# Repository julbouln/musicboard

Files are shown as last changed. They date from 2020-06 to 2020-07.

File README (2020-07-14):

This project only use a CODEC, a QuadSPI NOR-flash and a STM32F7 microcontroller to provide a complete MIDI + audio USB soundcard.

Continuation of https://github.com/julbouln/stm32f7discovery_midi_synth prototype. It now uses a memory and computing optimized version of https://github.com/schellingb/TinySoundFont and includes STM32 cubemx source code. A dedicated custom board is also provided even though STM32F746 discovery board is supported by the firmware.

Features:
- Composite USB audio, USB MIDI and USB mass storage
- Integrated SF2 MIDI syntheziser
- Easy SF2 soundfont customization with USB mass storage
- Mixed MIDI synthesis and raw audio

Custom board with minimal requirements:
- STM32F746VET6 LQFP100 320kb ram + 512kb flash
- S25FL256S 32mb nor flash
- WM8731 codec

Update SF2 font (Linux):
When connected, Linux should show the Flash as mass storage:
sd 6:0:0:0: [sdb] 8192 4096-byte logical blocks: (33.6 MB/32.0 MiB)
sd 6:0:0:0: [sdb] Write Protect is off
sd 6:0:0:0: [sdb] Mode Sense: 22 00 00 00
sd 6:0:0:0: [sdb] Write cache: disabled, read cache: enabled, doesn't support DPO or FUA
sd 6:0:0:0: [sdb] Attached SCSI removable disk
You just need to dd the sf2 file to the disk (can take several minutes):
# dd if=yourfont.sf2 of=/dev/sdb bs=4096

Update SF2 font (balena Etcher)
You can also update the SF2 using balena Etcher https://www.balena.io/etcher/. This program is intended for OS image, but you can use it for SF2:
- you will need to rename your extension from .sf2 to .bin so Etcher can accept the file
- Etcher will warn you that the image is not an OS, just hit continue and select SF2 ROM drive

LED should blink if the font is properly recognized.

Notes:
Firmware tested with arm-none-eabi-gcc 9.2.1 20191025
SF2 fonts tested:
- TimGM6mb http://www.timbrechbill.com/saxguru/Timidity.php
- GeneralUser GS http://www.schristiancollins.com/generaluser.php (custom board only, 32mb font)
Default make for STM32F746-DISCO board, use "make BOARD=MUSICBOARD" for custom board firmware.

TODO:
- bug: synthesis sometimes make a "click" noise
- feature: TinySoundFont does not fully implement SF2 (modulators)
- feature: Add MIDI IN/OUT uart interfaces
- feature: USB-MIDI to MIDI interface (add MIDI-IN and MIDI-OUT)
- feature: Audio IN
- feature: Add sysex for chorus & reverb control

Sources:
- https://github.com/STMicroelectronics/STM32CubeF7

SF2:
- https://github.com/schellingb/TinySoundFont

USB audio with asynchronous feedback
- https://github.com/dragonman225/stm32f469-usbaudio
- https://github.com/ada-sound/X-CUBE-USB-AUDIO
- https://github.com/Lefucjusz/Lefucjusz-USB-DAC

USB composite:
- https://github.com/sanuch14/STM32_CompositeHID_CDC

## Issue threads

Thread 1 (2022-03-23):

Ceci n'est pas un probleme

ukmaker, 2022-03-23:
Hi @julbouln and thanks for your work on this!

I'm about to try to port it to the Electrosmith Daisy Seed - any gotchas I should be aware of?

If you haven't seen it, it's an STM32H750 based board with WM8731, QSPI flash and RAM ( https://github.com/electro-smith/Hardware/blob/master/reference/daisy_seed/Daisy_Seed_Rev5_sch.pdf )

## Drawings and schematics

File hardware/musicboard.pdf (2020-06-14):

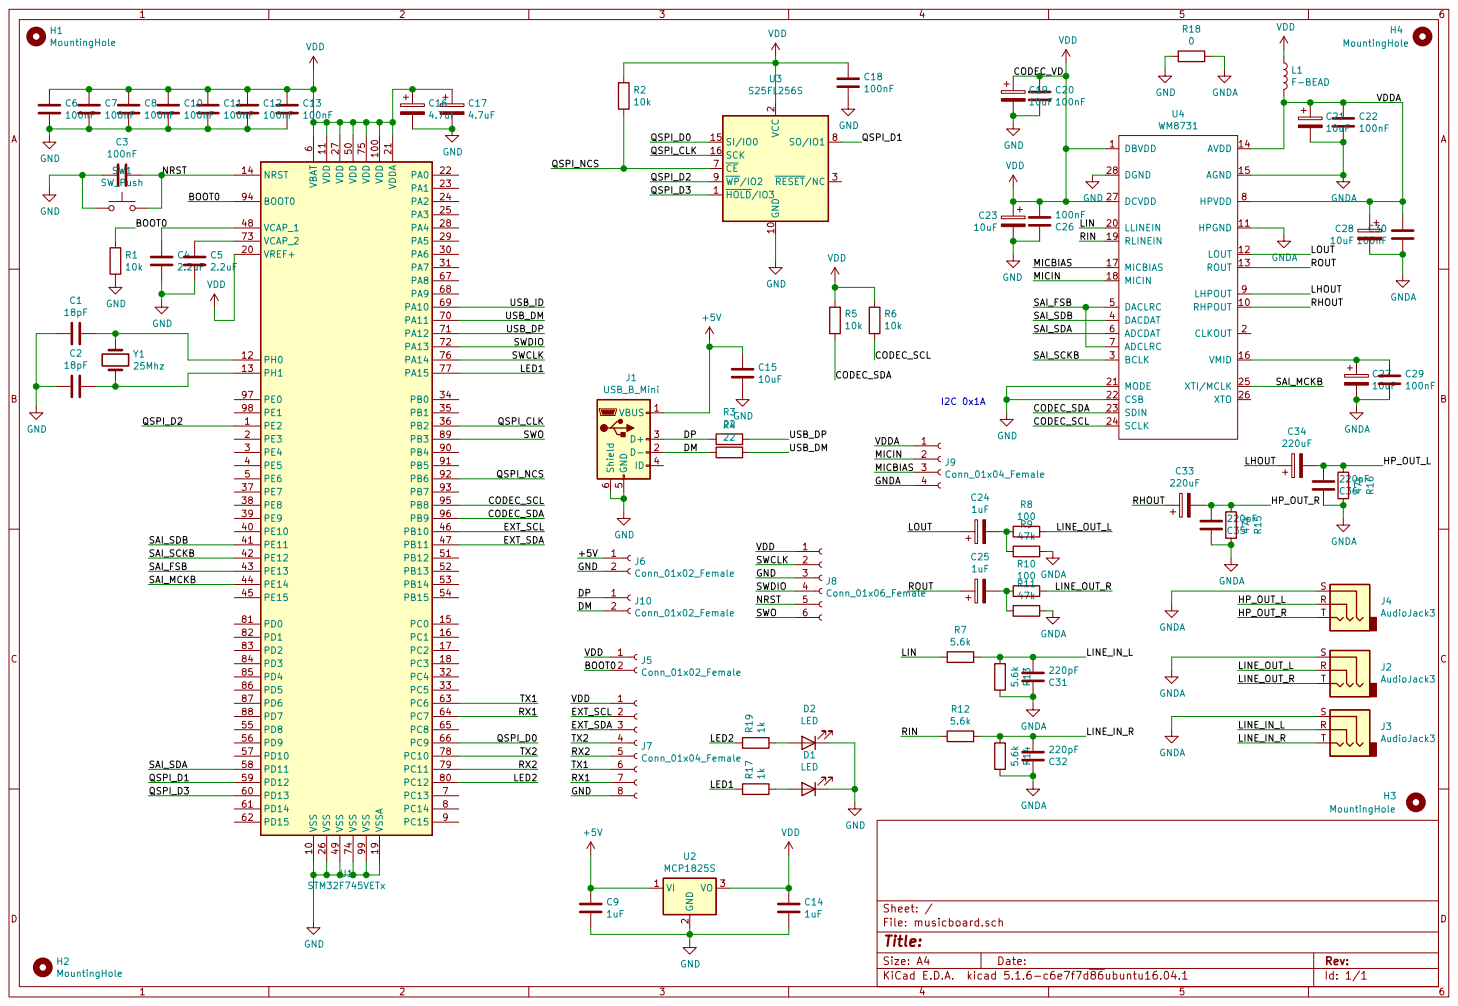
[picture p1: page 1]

2 RESET/NC 3 CE 7 SO/IO1 8 WP/IO2 9 U3 S25FL256S

6 VCAP_1 48 VCAP_2 73 VDD 100 VDD 11 VDD 27 VDD 50 VDD 75 VDDA 21 VREF+ 20 VSS 10 VSS 26 VSS 49 VSS 74 VSS 99 VSSA 19 U1 STM32F745VETx 1

Id: 1/1 Title: File: musicboard.sch Sheet: /

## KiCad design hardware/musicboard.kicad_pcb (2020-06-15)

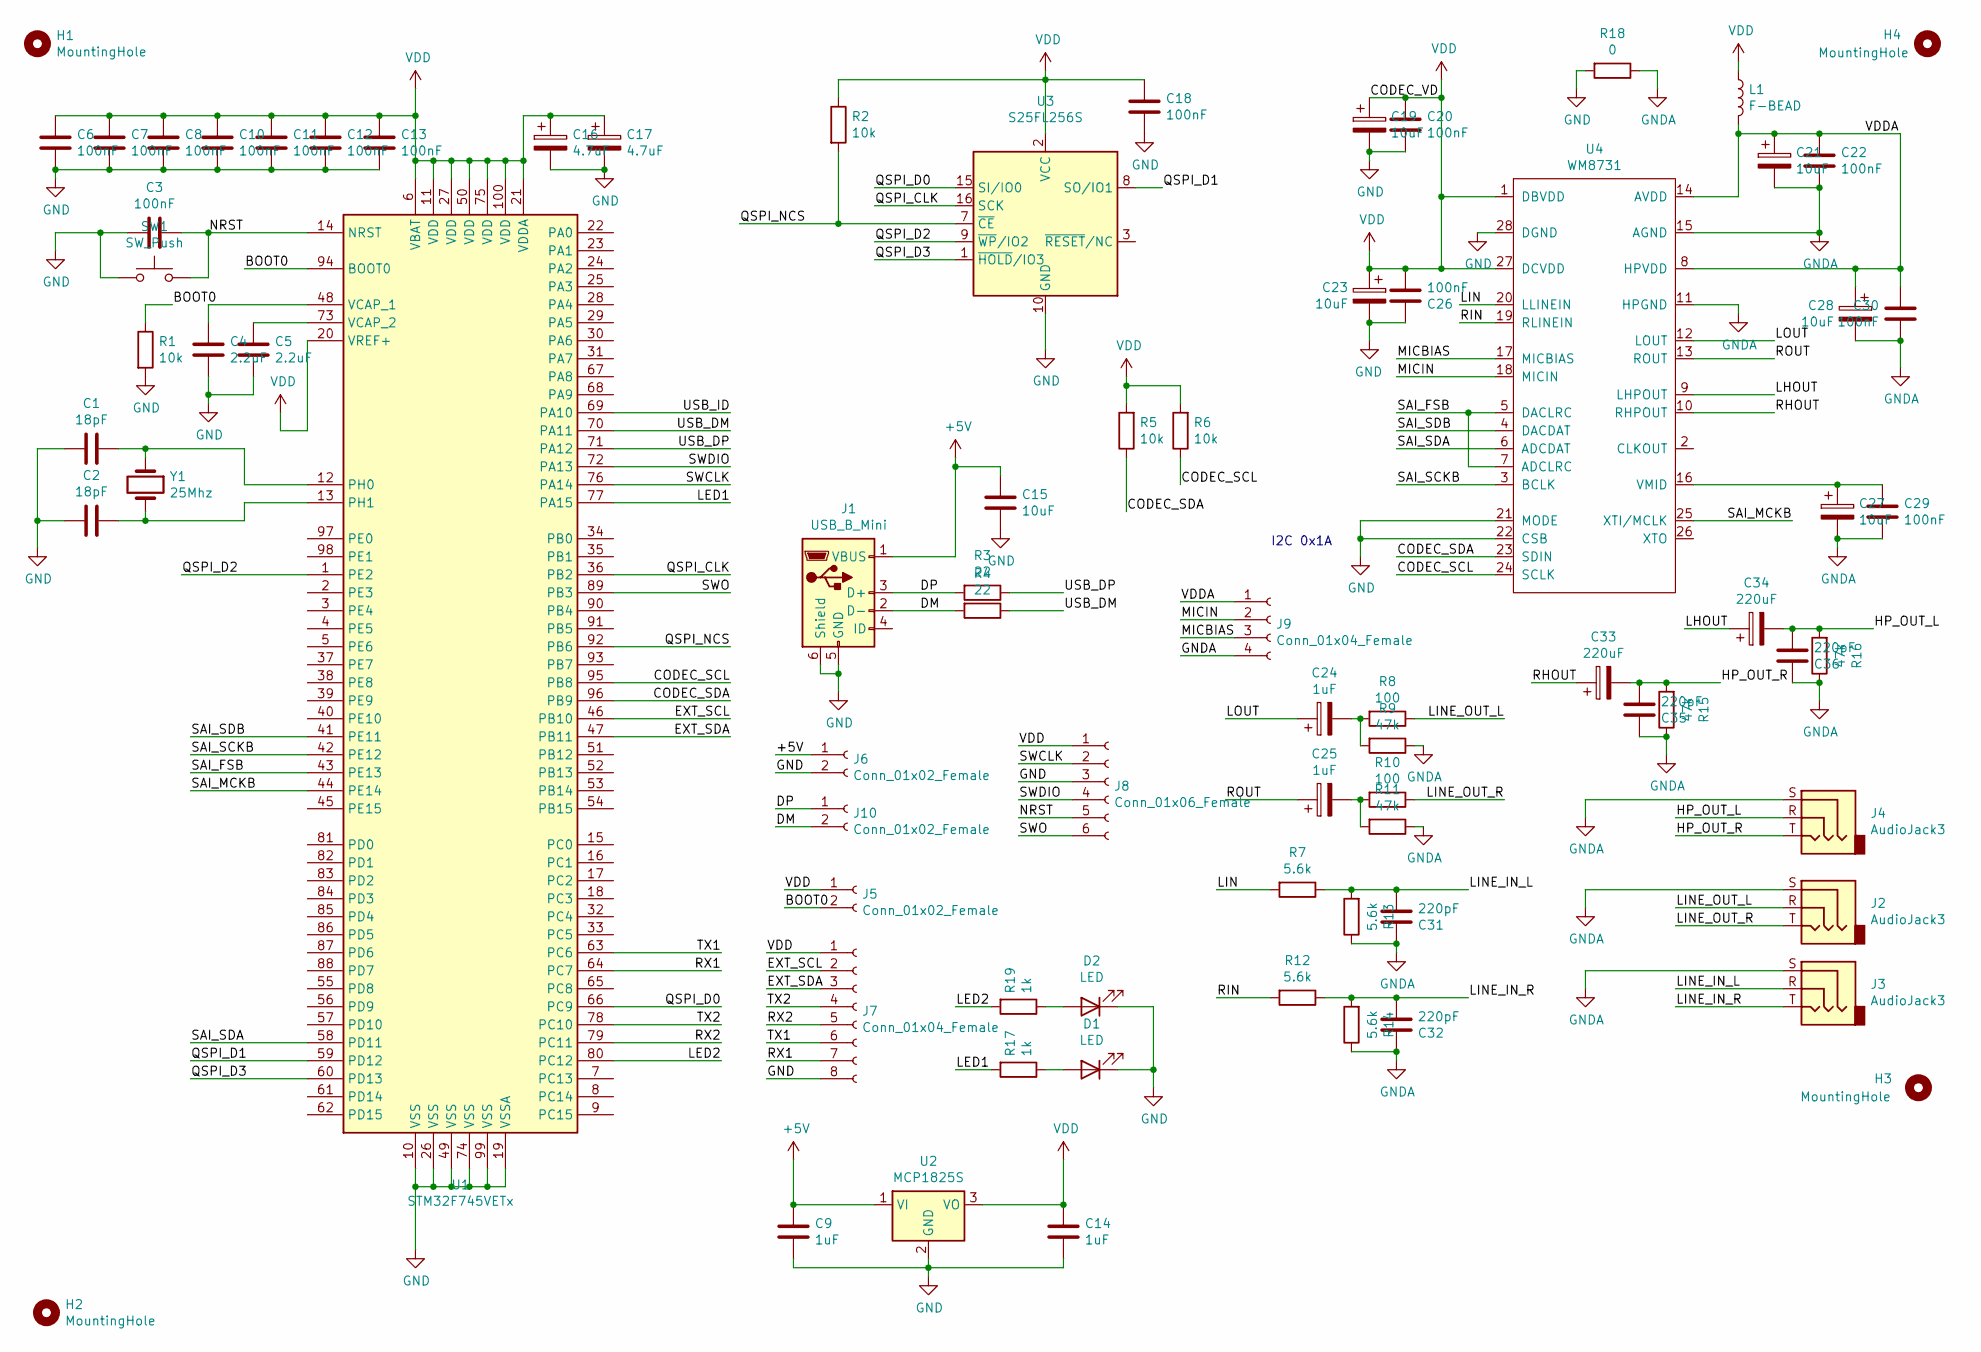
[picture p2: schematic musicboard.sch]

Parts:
C1, C2: 18pF; C_0603_1608Metric_Pad1.05x0.95mm_HandSolder
C3, C6, C7, C8, C10, C11, C12, C13, C18, C20, C22, C26, C29, C30: 100nF; C_0603_1608Metric_Pad1.05x0.95mm_HandSolder
C4, C5: 2.2uF; C_0603_1608Metric_Pad1.05x0.95mm_HandSolder
C9, C14: 1uF; C_0603_1608Metric_Pad1.05x0.95mm_HandSolder
C15, C19, C21, C23, C27, C28: 10uF; C_0805_2012Metric_Pad1.15x1.40mm_HandSolder
C16, C17: 4.7uF; C_0805_2012Metric_Pad1.15x1.40mm_HandSolder
C24, C25: 1uF; C_Elec_4x5.4
C31, C32, C35, C36: 220pF; C_0603_1608Metric_Pad1.05x0.95mm_HandSolder
C33, C34: 220uF; C_Elec_6.3x5.4
D1, D2: LED; LED_0603_1608Metric_Pad1.05x0.95mm_HandSolder
H1, H2, H3, H4: MountingHole; MountingHole_2.7mm_M2.5
J1: USB_B_Mini; USB-mini-B-0548190519
J2, J3, J4: AudioJack3; Jack_3.5mm_CUI_SJ1-3535NG_Horizontal
J5, J6, J10: Conn_01x02_Female; PinHeader_1x02_P2.54mm_Vertical
J7: Conn_01x04_Female; PinHeader_1x08_P2.54mm_Vertical
J8: Conn_01x06_Female; PinHeader_1x06_P2.54mm_Vertical
J9: Conn_01x04_Female; PinHeader_1x04_P2.54mm_Vertical
L1: F-BEAD; L_0805_2012Metric_Pad1.15x1.40mm_HandSolder
R1, R2, R5, R6: 10k; R_0603_1608Metric_Pad1.05x0.95mm_HandSolder
R3, R4: 22; R_0603_1608Metric_Pad1.05x0.95mm_HandSolder
R7, R12, R13, R14: 5.6k; R_0603_1608Metric_Pad1.05x0.95mm_HandSolder
R8, R10: 100; R_0603_1608Metric_Pad1.05x0.95mm_HandSolder
R9, R11, R15, R16: 47k; R_0603_1608Metric_Pad1.05x0.95mm_HandSolder
R17, R19: 1k; R_0603_1608Metric_Pad1.05x0.95mm_HandSolder
R18: 0; R_0805_2012Metric_Pad1.15x1.40mm_HandSolder
SW1: SW_Push; SW_SPST_B3U-3000P
U1: STM32F745VETx; LQFP-100_14x14mm_P0.5mm
U2: MCP1825S; SOT-223-3_TabPin2
U3: S25FL256S; SOIC-16W_7.5x10.3mm_P1.27mm
U4: WM8731; SSOP-28_5.3x10.2mm_P0.65mm
Y1: 25Mhz; Crystal_SMD_5032-2Pin_5.0x3.2mm_HandSoldering

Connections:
+5V: C9.1, C15.1, J1.1 (VBUS), J6.1, U2.1 (VI)
/BOOT0: J5.2, R1.1, U1.94 (BOOT0)
/CODEC_SCL: R6.1, U1.95 (PB8), U4.24 (SCLK)
/CODEC_SDA: R5.1, U1.96 (PB9), U4.23 (SDIN)
/DM: J1.2 (D-), J10.2, R4.2
/DP: J1.3 (D+), J10.1, R3.2
/EXT_SCL: J7.2, U1.46 (PB10)
/EXT_SDA: J7.3, U1.47 (PB11)
/HP_OUT_L: C34.2, C36.2, J4.R, R16.2
/HP_OUT_R: C33.2, C35.2, J4.T, R15.2
/LED1: R17.2, U1.77 (PA15)
/LED2: R19.2, U1.80 (PC12)
/LHOUT: C34.1, U4.9 (LHPOUT)
/LIN: R7.2, U4.20 (LLINEIN)
/LINE_IN_L: C31.2, J3.R, R7.1, R13.2
/LINE_IN_R: C32.2, J3.T, R12.1, R14.2
/LINE_OUT_L: J2.R, R8.1
/LINE_OUT_R: J2.T, R10.1
/LOUT: C24.1, U4.12 (LOUT)
/MICBIAS: J9.3, U4.17 (MICBIAS)
/MICIN: J9.2, U4.18 (MICIN)
/NRST: C3.1, J8.5, SW1.2, U1.14 (NRST)
/QSPI_CLK: U1.36 (PB2), U3.16 (SCK)
/QSPI_D0: U1.66 (PC9), U3.15 (SI/IO0)
/QSPI_D1: U1.59 (PD12), U3.8 (SO/IO1)
/QSPI_D2: U1.1 (PE2), U3.9 (~WP~/IO2)
/QSPI_D3: U1.60 (PD13), U3.1 (~HOLD~/IO3)
/QSPI_NCS: R2.2, U1.92 (PB6), U3.7 (~CE)
/RHOUT: C33.1, U4.10 (RHPOUT)
/RIN: R12.2, U4.19 (RLINEIN)
/ROUT: C25.1, U4.13 (ROUT)
/RX1: J7.7, U1.64 (PC7)
/RX2: J7.5, U1.79 (PC11)
/SAI_FSB: U1.43 (PE13), U4.5 (DACLRC), U4.7 (ADCLRC)
/SAI_MCKB: U1.44 (PE14), U4.25 (XTI/MCLK)
/SAI_SCKB: U1.42 (PE12), U4.3 (BCLK)
/SAI_SDA: U1.58 (PD11), U4.6 (ADCDAT)
/SAI_SDB: U1.41 (PE11), U4.4 (DACDAT)
/SWCLK: J8.2, U1.76 (PA14)
/SWDIO: J8.4, U1.72 (PA13)
/SWO: J8.6, U1.89 (PB3)
/TX1: J7.6, U1.63 (PC6)
/TX2: J7.4, U1.78 (PC10)
/USB_DM: R4.1, U1.70 (PA11)
/USB_DP: R3.1, U1.71 (PA12)
/USB_ID: U1.69 (PA10)
/VDDA: C21.1, C22.1, C28.1, C30.1, J9.1, L1.2, U4.8 (HPVDD), U4.14 (AVDD)
GND: C1.2, C2.2, C3.2, C4.2, C5.2, C6.2, C7.2, C8.2, C9.2, C10.2, C11.2, C12.2, C13.2, C14.2, C15.2, C16.2, C17.2, C18.2, C19.2, C20.2, C23.2, C26.1, D1.1 (K), D2.1 (K), J1.5 (GND), J1.6 (Shield), J6.2, J7.8, J8.3, R1.2, R18.2, SW1.1, U1.10 (VSS), U1.19 (VSSA), U1.26 (VSS), U1.49 (VSS), U1.74 (VSS), U1.99 (VSS), U2.2 (GND), U3.10 (GND), U4.21 (MODE), U4.22 (CSB), U4.28 (DGND)
GNDA: C21.2, C22.2, C27.2, C28.2, C29.2, C30.2, C31.1, C32.1, C35.1, C36.1, J2.S, J3.S, J4.S, J9.4, R9.1, R11.1, R13.1, R14.1, R15.1, R16.1, R18.1, U4.11 (HPGND), U4.15 (AGND)
unnamed: C1.1, U1.12 (PH0), Y1.1
unnamed: C2.1, U1.13 (PH1), Y1.2
unnamed: C4.1, U1.48 (VCAP_1)
unnamed: C5.1, U1.73 (VCAP_2)
unnamed: C24.2, R8.2, R9.2
unnamed: C25.2, R10.2, R11.2
unnamed: C27.1, C29.1, U4.16 (VMID)
unnamed: D1.2 (A), R17.1
unnamed: D2.2 (A), R19.1
VDD: C6.1, C7.1, C8.1, C10.1, C11.1, C12.1, C13.1, C14.1, C16.1, C17.1, C18.1, C19.1, C20.1, C23.1, C26.2, J5.1, J7.1, J8.1, L1.1, R2.1, R5.2, R6.2, U1.6 (VBAT), U1.11 (VDD), U1.20 (VREF+), U1.21 (VDDA), U1.27 (VDD), U1.50 (VDD), U1.75 (VDD), U1.100 (VDD), U2.3 (VO), U3.2 (VCC), U4.1 (DBVDD), U4.27 (DCVDD)

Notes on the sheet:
I2C 0x1A

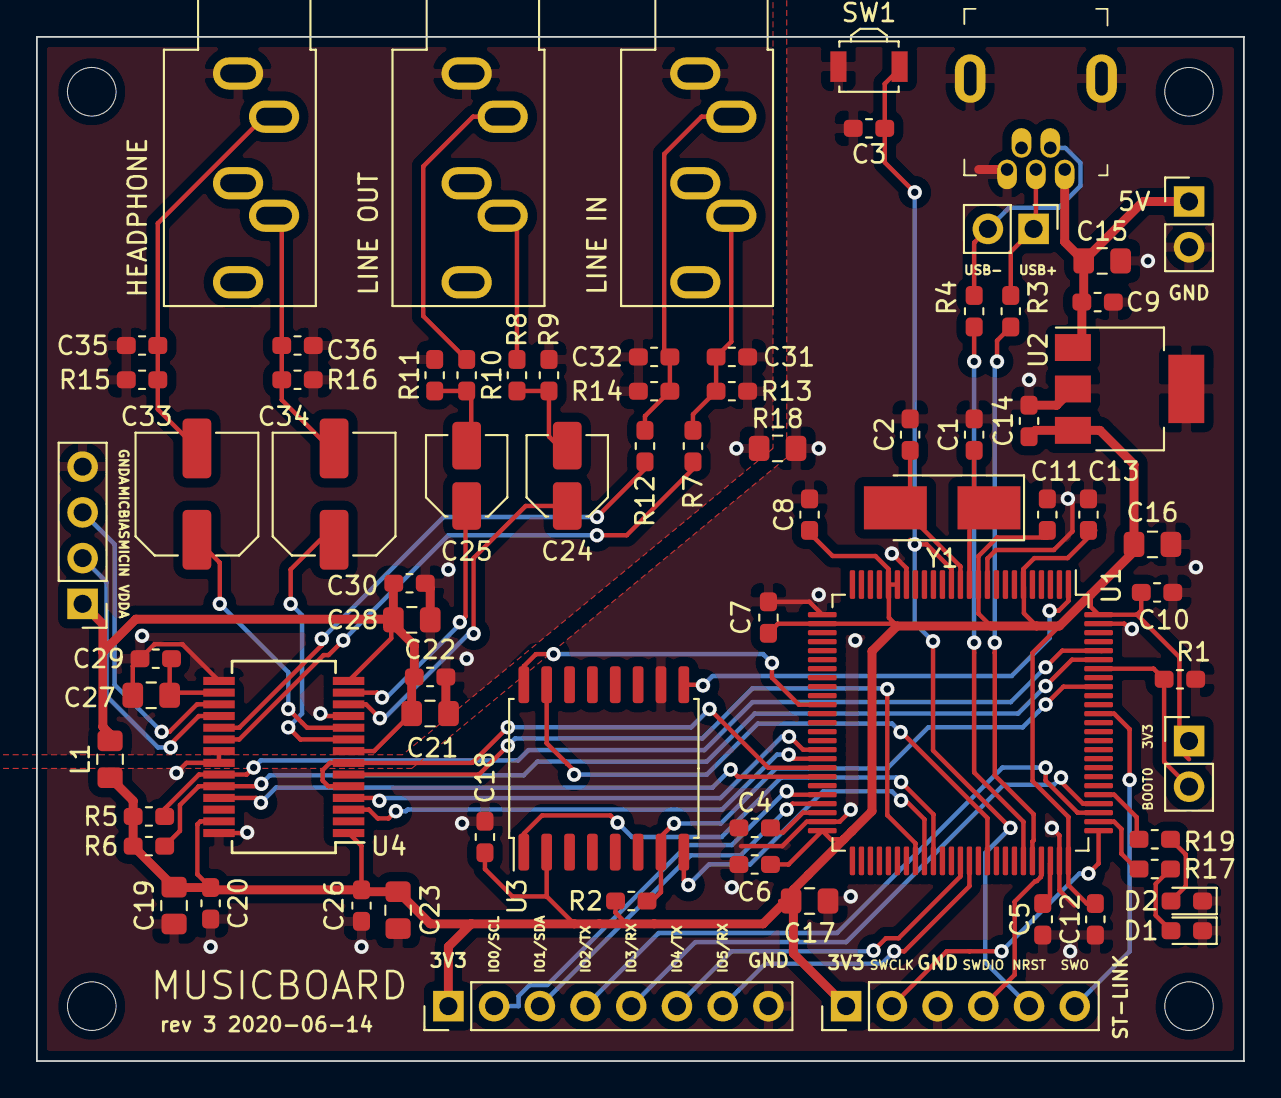
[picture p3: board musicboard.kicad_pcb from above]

Board: 2 copper layers, 67.1 x 56.9 mm, 78 parts (0 on the bottom side), 58 nets.

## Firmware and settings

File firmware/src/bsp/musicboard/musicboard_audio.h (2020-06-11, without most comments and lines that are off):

#define __MUSICBOARD_AUDIO_H
#ifdef __cplusplus
 extern "C" {
#endif
#include "wm8731.h"
#include "musicboard.h"
#define CODEC_AUDIOFRAME_SLOT_0123           SAI_SLOTACTIVE_0 | SAI_SLOTACTIVE_1 | SAI_SLOTACTIVE_2 | SAI_SLOTACTIVE_3
#define CODEC_AUDIOFRAME_SLOT_02             SAI_SLOTACTIVE_0 | SAI_SLOTACTIVE_2
#define CODEC_AUDIOFRAME_SLOT_13             SAI_SLOTACTIVE_1 | SAI_SLOTACTIVE_3
#define AUDIO_OUT_SAIx                           SAI2_Block_B
#define AUDIO_OUT_SAIx_CLK_ENABLE()              __HAL_RCC_SAI2_CLK_ENABLE()
#define AUDIO_OUT_SAIx_CLK_DISABLE()             __HAL_RCC_SAI2_CLK_DISABLE()
#define AUDIO_OUT_SAIx_SCK_AF                    GPIO_AF10_SAI2
#define AUDIO_OUT_SAIx_FS_SD_MCLK_AF             GPIO_AF10_SAI2
#define AUDIO_OUT_SAIx_MCLK_ENABLE()             __HAL_RCC_GPIOE_CLK_ENABLE()
#define AUDIO_OUT_SAIx_MCLK_GPIO_PORT            GPIOE
#define AUDIO_OUT_SAIx_MCLK_PIN                  GPIO_PIN_14
#define AUDIO_OUT_SAIx_SCK_SD_ENABLE()           __HAL_RCC_GPIOE_CLK_ENABLE()
#define AUDIO_OUT_SAIx_SCK_SD_GPIO_PORT          GPIOE
#define AUDIO_OUT_SAIx_SCK_PIN                   GPIO_PIN_12
#define AUDIO_OUT_SAIx_SD_PIN                    GPIO_PIN_11
#define AUDIO_OUT_SAIx_FS_ENABLE()               __HAL_RCC_GPIOE_CLK_ENABLE()
#define AUDIO_OUT_SAIx_FS_GPIO_PORT              GPIOE
#define AUDIO_OUT_SAIx_FS_PIN                    GPIO_PIN_13
#define AUDIO_OUT_SAIx_DMAx_CLK_ENABLE()         __HAL_RCC_DMA2_CLK_ENABLE()
#define AUDIO_OUT_SAIx_DMAx_STREAM               DMA2_Stream7
#define AUDIO_OUT_SAIx_DMAx_CHANNEL              DMA_CHANNEL_0
#define AUDIO_OUT_SAIx_DMAx_IRQ                  DMA2_Stream7_IRQn
#define AUDIO_OUT_SAIx_DMAx_PERIPH_DATA_SIZE     DMA_PDATAALIGN_HALFWORD
#define AUDIO_OUT_SAIx_DMAx_MEM_DATA_SIZE        DMA_MDATAALIGN_HALFWORD
#define DMA_MAX_SZE                              ((uint16_t)0xFFFF)
#define AUDIO_OUT_SAIx_DMAx_IRQHandler           DMA2_Stream7_IRQHandler
#define AUDIO_OUT_IRQ_PREPRIO                    ((uint32_t)0x0E)
#define AUDIO_IN_SAIx                            SAI2_Block_A
#define AUDIO_IN_SAIx_CLK_ENABLE()               __HAL_RCC_SAI2_CLK_ENABLE()
#define AUDIO_IN_SAIx_CLK_DISABLE()              __HAL_RCC_SAI2_CLK_DISABLE()
#define AUDIO_IN_SAIx_SD_AF                      GPIO_AF10_SAI2
#define AUDIO_IN_SAIx_SD_ENABLE()                __HAL_RCC_GPIOD_CLK_ENABLE()
#define AUDIO_IN_SAIx_SD_GPIO_PORT               GPIOD
#define AUDIO_IN_SAIx_SD_PIN                     GPIO_PIN_11
#define AUDIO_IN_INT_GPIO_ENABLE()               __HAL_RCC_GPIOH_CLK_ENABLE()
#define AUDIO_IN_INT_GPIO_PORT                   GPIOH
#define AUDIO_IN_INT_GPIO_PIN                    GPIO_PIN_15
#define AUDIO_IN_INT_IRQ                         EXTI15_10_IRQn
#define AUDIO_IN_SAIx_DMAx_CLK_ENABLE()          __HAL_RCC_DMA2_CLK_ENABLE()
#define AUDIO_IN_SAIx_DMAx_STREAM                DMA2_Stream4
#define AUDIO_IN_SAIx_DMAx_CHANNEL               DMA_CHANNEL_3
#define AUDIO_IN_SAIx_DMAx_IRQ                   DMA2_Stream4_IRQn
#define AUDIO_IN_SAIx_DMAx_PERIPH_DATA_SIZE      DMA_PDATAALIGN_HALFWORD
#define AUDIO_IN_SAIx_DMAx_MEM_DATA_SIZE         DMA_MDATAALIGN_HALFWORD
#define AUDIO_IN_SAIx_DMAx_IRQHandler            DMA2_Stream4_IRQHandler
#define AUDIO_IN_INT_IRQHandler                  EXTI15_10_IRQHandler
#define AUDIO_IN_IRQ_PREPRIO                     ((uint32_t)0x0F)
#define AUDIODATA_SIZE                      ((uint16_t)2)
#define AUDIO_OK                            ((uint8_t)0)
#define AUDIO_ERROR                         ((uint8_t)1)
#define AUDIO_TIMEOUT                       ((uint8_t)2)
#define DEFAULT_AUDIO_IN_FREQ               I2S_AUDIOFREQ_16K
#define DEFAULT_AUDIO_IN_BIT_RESOLUTION     ((uint8_t)16)
#define DEFAULT_AUDIO_IN_CHANNEL_NBR        ((uint8_t)2)
#define DEFAULT_AUDIO_IN_VOLUME             ((uint16_t)64)
#define CODEC_RESET_DELAY                   ((uint8_t)5)
#define OUTPUT_DEVICE_HEADPHONE1 OUTPUT_DEVICE_HEADPHONE
#define OUTPUT_DEVICE_HEADPHONE2 OUTPUT_DEVICE_SPEAKER
extern __IO uint16_t AudioInVolume;
#define DMA_MAX(x)           (((x) <= DMA_MAX_SZE)? (x):DMA_MAX_SZE)
uint8_t BSP_AUDIO_OUT_Init(uint16_t OutputDevice, uint8_t Volume, uint32_t AudioFreq);
uint8_t BSP_AUDIO_OUT_Play(uint16_t* pBuffer, uint32_t Size);
void    BSP_AUDIO_OUT_ChangeBuffer(uint16_t *pData, uint16_t Size);
uint8_t BSP_AUDIO_OUT_Pause(void);
uint8_t BSP_AUDIO_OUT_Resume(void);
uint8_t BSP_AUDIO_OUT_Stop(uint32_t Option);
uint8_t BSP_AUDIO_OUT_SetVolume(uint8_t Volume);
void    BSP_AUDIO_OUT_SetFrequency(uint32_t AudioFreq);
void    BSP_AUDIO_OUT_SetAudioFrameSlot(uint32_t AudioFrameSlot);
uint8_t BSP_AUDIO_OUT_SetMute(uint32_t Cmd);
uint8_t BSP_AUDIO_OUT_SetOutputMode(uint8_t Output);
void    BSP_AUDIO_OUT_DeInit(void);
void    BSP_AUDIO_OUT_TransferComplete_CallBack(void);
void    BSP_AUDIO_OUT_HalfTransfer_CallBack(void);
void    BSP_AUDIO_OUT_Error_CallBack(void);
void  BSP_AUDIO_OUT_ClockConfig(SAI_HandleTypeDef *hsai, uint32_t AudioFreq, void *Params);
void  BSP_AUDIO_OUT_MspInit(SAI_HandleTypeDef *hsai, void *Params);
void  BSP_AUDIO_OUT_MspDeInit(SAI_HandleTypeDef *hsai, void *Params);
uint8_t BSP_AUDIO_IN_Init(uint32_t AudioFreq, uint32_t BitRes, uint32_t ChnlNbr);
uint8_t BSP_AUDIO_IN_InitEx(uint16_t InputDevice, uint32_t AudioFreq, uint32_t BitRes, uint32_t ChnlNbr);
uint8_t BSP_AUDIO_IN_OUT_Init(uint16_t InputDevice, uint16_t OutputDevice, uint32_t AudioFreq, uint32_t BitRes, uint32_t ChnlNbr);
uint8_t BSP_AUDIO_IN_Record(uint16_t *pData, uint32_t Size);
uint8_t BSP_AUDIO_IN_Stop(uint32_t Option);
uint8_t BSP_AUDIO_IN_Pause(void);
uint8_t BSP_AUDIO_IN_Resume(void);
uint8_t BSP_AUDIO_IN_SetVolume(uint8_t Volume);
void    BSP_AUDIO_IN_DeInit(void);
void    BSP_AUDIO_IN_TransferComplete_CallBack(void);
void    BSP_AUDIO_IN_HalfTransfer_CallBack(void);
void    BSP_AUDIO_IN_Error_CallBack(void);
void  BSP_AUDIO_IN_MspInit(SAI_HandleTypeDef *hsai, void *Params);
void  BSP_AUDIO_IN_MspDeInit(SAI_HandleTypeDef *hsai, void *Params);
#ifdef __cplusplus
}
#endif

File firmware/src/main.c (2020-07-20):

#include "main.h"

USBD_HandleTypeDef USBD_Device;
TIM_HandleTypeDef    TimHandle;

/* Private function prototypes -----------------------------------------------*/
static void SystemClock_Config(void);
static void Error_Handler(void);
static void MPU_Config(void);
static void CPU_CACHE_Enable(void);

#ifdef USE_FREERTOS

osThreadId_t led_handle, synth_handle, midi_handle;
osSemaphoreId_t synth_sem;
osMutexId_t synth_mutex;

osMessageQueueId_t midi_queue;

uint8_t synthesized = 0;
#else
uint8_t synthesized = 1;
#endif

uint8_t global_buf[AUDIO_BUF_SIZE];

void BSP_AUDIO_OUT_HalfTransfer_CallBack(void)
{
  if(synthesized) 
  {
    synth_update(global_buf, 0, AUDIO_BUF_SIZE / 2);
    audio_update(global_buf, 0, AUDIO_BUF_SIZE / 2);
  } else {
    // skip half/frame
    memset(&global_buf[0], 0, AUDIO_BUF_SIZE / 2);
  }
}

void BSP_AUDIO_OUT_TransferComplete_CallBack(void)
{
  if(synthesized) {
    synth_update(global_buf, AUDIO_BUF_SIZE / 2, AUDIO_BUF_SIZE / 2);
    audio_update(global_buf, AUDIO_BUF_SIZE / 2, AUDIO_BUF_SIZE / 2);
  } else {
    // skip half/frame
    memset(&global_buf[0] + AUDIO_BUF_SIZE / 2, 0, AUDIO_BUF_SIZE / 2);
  }

#ifdef USE_FREERTOS
  osSemaphoreRelease(synth_sem);
#endif
}

#ifdef USE_FREERTOS
void vApplicationIdleHook( void )
{
  while (1)
  {
    __WFI();
  }
}

void led_task(void *argument)
{
  while (1) {
    if (synth_available()) {
      BSP_LED_Toggle(LED1);
      osDelay(1000);
    } else {
      if(QSPI_is_writing()) {
        BSP_LED_Toggle(LED1);
        osDelay(100);        
      }
    }
    osThreadYield();
  }
}

void midi_task(void *argument)
{
  while (1) {
    if (synth_available()) {
      struct midi_message midi_msg;

      osStatus_t status = osMessageQueueGet(midi_queue, &midi_msg, NULL, osWaitForever);
      if (status == osOK) {
#ifdef LED2_PIN
        BSP_LED_On(LED2);
#endif
        synth_midi_process(midi_msg.data, midi_msg.len);
#ifdef LED2_PIN
        BSP_LED_Off(LED2);
#endif
      }
    }
    osThreadYield();
  }
}

void synth_task(void *argument)
{
  while (1) {
    osSemaphoreAcquire(synth_sem, osWaitForever);
    synthesized = 0;
    synth_render(0, AUDIO_BUF_SIZE/2);
    synthesized = 1;
    synth_render(AUDIO_BUF_SIZE/2, AUDIO_BUF_SIZE/2);
    synthesized = 2;
    osThreadYield();
  }
}
#endif

void led_init() {
  /* Configure LED1 */
  BSP_LED_Init(LED1);
#ifdef LED2_PIN
  BSP_LED_Init(LED2);
#endif

  BSP_LED_Off(LED1);
#ifdef LED2_PIN
  BSP_LED_Off(LED2);
#endif
}

void usb_init() {
#ifdef MUCISBOARD_USB_COMPOSITE
  /* Make the connection and initialize to USB_OTG/usbdc_core */
  USBD_Init(&USBD_Device, &MUSICBOARD_Desc, 0);
  USBD_RegisterClass(&USBD_Device, &USBD_Composite_ClassDriver);
  USBD_Composite_RegisterInterface(&USBD_Device);
#else
#ifdef MUCISBOARD_USB_MIDI_ONLY
  USBD_Init(&USBD_Device, &MUSICBOARD_Desc, 0);
  USBD_RegisterClass(&USBD_Device, &USBD_Midi_ClassDriver);
  USBD_Composite_RegisterInterface(&USBD_Device);
#endif

#ifdef MUCISBOARD_USB_AUDIO_ONLY
  USBD_Init(&USBD_Device, &MUSICBOARD_Desc, 0);
  USBD_RegisterClass(&USBD_Device, &USBD_AUDIO);
  USBD_Composite_RegisterInterface(&USBD_Device);
#endif

#ifdef MUSICBOARD_USB_MSC_ONLY
  USBD_Init(&USBD_Device, &MUSICBOARD_Desc, 0);
  USBD_RegisterClass(&USBD_Device, &USBD_MSC);
  USBD_MSC_RegisterStorage(&USBD_Device, &USBD_DISK_fops);
#endif
#endif

  USBD_Start(&USBD_Device);
}

void app_main(void *argument) {

}

int main(void)
{
  /* Configure the MPU attributes as Write Through */
  MPU_Config();

  /* Enable the CPU Cache */
  CPU_CACHE_Enable();

  /* STM32F7xx HAL library initialization */
  HAL_Init();

  /* Configure the system clock to 200 MHz */
  SystemClock_Config();

  led_init();

  setbuf(stdout, NULL);
  HAL_Delay(100);

  QSPI_init();

  HAL_Delay(100);

  audio_init();
  audio_buffer_init();

  BSP_AUDIO_OUT_Init(OUTPUT_DEVICE_AUTO, MASTER_VOLUME, SAMPLE_RATE);
  BSP_AUDIO_OUT_SetAudioFrameSlot(CODEC_AUDIOFRAME_SLOT_02);  // PCM 2-channel

  memset(global_buf, 0, AUDIO_BUF_SIZE);
  BSP_AUDIO_OUT_Play((uint16_t *)&global_buf[0], AUDIO_BUF_SIZE);

  usb_init();

  synth_init();
  synth_buffer_init();

#ifdef USE_FREERTOS
  osKernelInitialize();

  synth_sem = osSemaphoreNew (1, 1, NULL);
  synth_mutex = osMutexNew (NULL);

#ifdef QUEUED_MIDI_MESSAGES
  midi_queue = osMessageQueueNew(512, sizeof(struct midi_message), NULL);
#endif
  osThreadAttr_t led_thr_attr = {
    .priority = osPriorityLow
  };
#ifdef QUEUED_MIDI_MESSAGES
  osThreadAttr_t midi_thr_attr = {
    .priority = osPriorityHigh,
    .stack_size = 4096
  };
#endif
  osThreadAttr_t synth_thr_attr = {
    .priority = osPriorityRealtime,
    .stack_size = 4096
  };

  led_handle = osThreadNew(led_task, NULL, &led_thr_attr);
#ifdef QUEUED_MIDI_MESSAGES
  midi_handle = osThreadNew(midi_task, NULL, &midi_thr_attr);
#endif
  synth_handle = osThreadNew(synth_task, NULL, &synth_thr_attr);

  osKernelStart();
#else
  timer_init();
#endif

  while (1)
  {
    __WFI();
  }
}


void timer_init() {
  /* Prescaler declaration */
  uint32_t uwPrescalerValue = 0;
  uwPrescalerValue = (uint32_t)((SystemCoreClock / 2) / 10000) - 1;

  /* Set TIMx instance */
  TimHandle.Instance = TIM3;

  /* Initialize TIMx peripheral as follows:
       + Period = 10000 - 1
       + Prescaler = ((SystemCoreClock / 2)/10000) - 1
       + ClockDivision = 0
       + Counter direction = Up
  */
  TimHandle.Init.Period            = 10000 - 1;
  TimHandle.Init.Prescaler         = uwPrescalerValue;
  TimHandle.Init.ClockDivision     = TIM_CLOCKDIVISION_DIV1;
  TimHandle.Init.CounterMode       = TIM_COUNTERMODE_UP;
  TimHandle.Init.RepetitionCounter = 0;
  TimHandle.Init.AutoReloadPreload = TIM_AUTORELOAD_PRELOAD_DISABLE;
  if (HAL_TIM_Base_Init(&TimHandle) != HAL_OK)
  {
    /* Initialization Error */
    Error_Handler();
  }

  /*##-2- Start the TIM Base generation in interrupt mode ####################*/
  /* Start Channel1 */
  if (HAL_TIM_Base_Start_IT(&TimHandle) != HAL_OK)
  {
    /* Starting Error */
    Error_Handler();
  }
}

void HAL_TIM_PeriodElapsedCallback(TIM_HandleTypeDef *htim)
{
  if (htim->Instance == TIM3) {
    if (synth_available()) {
      BSP_LED_Toggle(LED1);
    }
  }
}

/**
  * @brief  Clock Config.
  * @param  hsai: might be required to set audio peripheral predivider if any.
  * @param  AudioFreq: Audio frequency used to play the audio stream.
  * @note   This API is called by BSP_AUDIO_OUT_Init() and BSP_AUDIO_OUT_SetFrequency()
  *         Being __weak it can be overwritten by the application
  * @retval None
  */
void BSP_AUDIO_OUT_ClockConfig(SAI_HandleTypeDef *hsai, uint32_t AudioFreq, void *Params)
{
  RCC_PeriphCLKInitTypeDef RCC_ExCLKInitStruct;

  HAL_RCCEx_GetPeriphCLKConfig(&RCC_ExCLKInitStruct);

  /* Set the PLL configuration according to the audio frequency */
  if ((AudioFreq == AUDIO_FREQUENCY_11K) || (AudioFreq == AUDIO_FREQUENCY_22K) || (AudioFreq == AUDIO_FREQUENCY_44K))
  {
    /* Configure PLLSAI prescalers */
    /* PLLI2S_VCO: VCO_429M
    SAI_CLK(first level) = PLLI2S_VCO/PLLSAIQ = 429/2 = 214.5 Mhz
    SAI_CLK_x = SAI_CLK(first level)/PLLI2SDivQ = 214.5/19 = 11.289 Mhz */
    RCC_ExCLKInitStruct.PeriphClockSelection = RCC_PERIPHCLK_SAI2;
    RCC_ExCLKInitStruct.Sai2ClockSelection = RCC_SAI2CLKSOURCE_PLLI2S;
    RCC_ExCLKInitStruct.PLLI2S.PLLI2SP = 8;
    RCC_ExCLKInitStruct.PLLI2S.PLLI2SN = 429;
    RCC_ExCLKInitStruct.PLLI2S.PLLI2SQ = 2;
    RCC_ExCLKInitStruct.PLLI2SDivQ = 19;
    HAL_RCCEx_PeriphCLKConfig(&RCC_ExCLKInitStruct);
  }
  else /* AUDIO_FREQUENCY_8K, AUDIO_FREQUENCY_16K, AUDIO_FREQUENCY_48K), AUDIO_FREQUENCY_96K */
  {
    /* SAI clock config
    PLLI2S_VCO: VCO_344M
    SAI_CLK(first level) = PLLI2S_VCO/PLLSAIQ = 344/7 = 49.142 Mhz
    SAI_CLK_x = SAI_CLK(first level)/PLLI2SDivQ = 49.142/1 = 49.142 Mhz */
    RCC_ExCLKInitStruct.PeriphClockSelection = RCC_PERIPHCLK_SAI2;
    RCC_ExCLKInitStruct.Sai2ClockSelection = RCC_SAI2CLKSOURCE_PLLI2S;
    RCC_ExCLKInitStruct.PLLI2S.PLLI2SP = 8;
    RCC_ExCLKInitStruct.PLLI2S.PLLI2SN = 344;
    RCC_ExCLKInitStruct.PLLI2S.PLLI2SQ = 7;
    RCC_ExCLKInitStruct.PLLI2SDivQ = 1;
    HAL_RCCEx_PeriphCLKConfig(&RCC_ExCLKInitStruct);
  }
}


/**
  * @brief  System Clock Configuration
  *         The system Clock is configured as follow :
  *            System Clock source            = PLL (HSE)
  *            SYSCLK(Hz)                     = 200000000
  *            HCLK(Hz)                       = 200000000
  *            AHB Prescaler                  = 1
  *            APB1 Prescaler                 = 4
  *            APB2 Prescaler                 = 2
  *            HSE Frequency(Hz)              = 25000000
  *            PLL_M                          = 25
  *            PLL_N                          = 400
  *            PLL_P                          = 2
  *            PLL_Q                          = 8
  *            VDD(V)                         = 3.3
  *            Main regulator output voltage  = Scale1 mode
  *            Flash Latency(WS)              = 6
  * @param  None
  * @retval None
  */


/**
  * @brief TIM MSP Initialization
  *        This function configures the hardware resources used in this example:
  *           - Peripheral's clock enable
  * @param htim: TIM handle pointer
  * @retval None
  */
void HAL_TIM_Base_MspInit(TIM_HandleTypeDef *htim)
{
  /*##-1- Enable peripheral clock #################################*/
  /* TIMx Peripheral clock enable */
  __HAL_RCC_TIM3_CLK_ENABLE();

  /*##-2- Configure the NVIC for TIMx ########################################*/
  /* Set the TIMx priority */
  HAL_NVIC_SetPriority(TIM3_IRQn, 3, 0);

  /* Enable the TIMx global Interrupt */
  HAL_NVIC_EnableIRQ(TIM3_IRQn);
}


// 200 mhz - don't know why but 216 mhz hang
void SystemClock_Config(void)
{
  RCC_ClkInitTypeDef RCC_ClkInitStruct;
  RCC_OscInitTypeDef RCC_OscInitStruct;
  HAL_StatusTypeDef ret = HAL_OK;

  /* Enable HSE Oscillator and activate PLL with HSE as source */
  RCC_OscInitStruct.OscillatorType = RCC_OSCILLATORTYPE_HSE;
  RCC_OscInitStruct.HSEState = RCC_HSE_ON;
  RCC_OscInitStruct.HSIState = RCC_HSI_OFF;
  RCC_OscInitStruct.PLL.PLLState = RCC_PLL_ON;
  RCC_OscInitStruct.PLL.PLLSource = RCC_PLLSOURCE_HSE;
  RCC_OscInitStruct.PLL.PLLM = 25;
#ifdef FREQ_216
  RCC_OscInitStruct.PLL.PLLN = 432;
#else
  RCC_OscInitStruct.PLL.PLLN = 400;
#endif
  RCC_OscInitStruct.PLL.PLLP = RCC_PLLP_DIV2;
#ifdef FREQ_216
  RCC_OscInitStruct.PLL.PLLQ = 9;
#else
  RCC_OscInitStruct.PLL.PLLQ = 8;
#endif

  ret = HAL_RCC_OscConfig(&RCC_OscInitStruct);
  if (ret != HAL_OK)
  {
    while (1) { ; }
  }

  /* Activate the OverDrive to reach the 200 MHz Frequency */
  ret = HAL_PWREx_EnableOverDrive();
  if (ret != HAL_OK)
  {
    while (1) { ; }
  }

  /* Select PLL as system clock source and configure the HCLK, PCLK1 and PCLK2 clocks dividers */
  RCC_ClkInitStruct.ClockType = (RCC_CLOCKTYPE_SYSCLK | RCC_CLOCKTYPE_HCLK | RCC_CLOCKTYPE_PCLK1 | RCC_CLOCKTYPE_PCLK2);
  RCC_ClkInitStruct.SYSCLKSource = RCC_SYSCLKSOURCE_PLLCLK;
  RCC_ClkInitStruct.AHBCLKDivider = RCC_SYSCLK_DIV1;
  RCC_ClkInitStruct.APB1CLKDivider = RCC_HCLK_DIV4;
  RCC_ClkInitStruct.APB2CLKDivider = RCC_HCLK_DIV2;

#ifdef FREQ_216
  ret = HAL_RCC_ClockConfig(&RCC_ClkInitStruct, FLASH_LATENCY_7);
#else
  ret = HAL_RCC_ClockConfig(&RCC_ClkInitStruct, FLASH_LATENCY_6);
#endif

  if (ret != HAL_OK)
  {
    while (1) { ; }
  }
}

/**
  * @brief  Configure the MPU attributes as Write Through for SDRAM.
  * @note   The Base Address for SDRAM is 0xC0000000.
  *         The Region Size is 8MB, it is related to SDRAM memory size.
  * @param  None
  * @retval None
  */
static void MPU_Config(void)
{
  MPU_Region_InitTypeDef MPU_InitStruct;

  /* Disable the MPU */
  HAL_MPU_Disable();

  /* Configure the MPU attributes as WT for SDRAM */
  MPU_InitStruct.Enable = MPU_REGION_ENABLE;
  MPU_InitStruct.BaseAddress = 0x20010000;
  MPU_InitStruct.Size = MPU_REGION_SIZE_256KB;

  MPU_InitStruct.AccessPermission = MPU_REGION_FULL_ACCESS;
  MPU_InitStruct.IsBufferable = MPU_ACCESS_NOT_BUFFERABLE;
  MPU_InitStruct.IsCacheable = MPU_ACCESS_CACHEABLE;
  MPU_InitStruct.IsShareable = MPU_ACCESS_NOT_SHAREABLE;
  MPU_InitStruct.Number = MPU_REGION_NUMBER0;
  MPU_InitStruct.TypeExtField = MPU_TEX_LEVEL0;
  MPU_InitStruct.SubRegionDisable = 0x00;
  MPU_InitStruct.DisableExec = MPU_INSTRUCTION_ACCESS_ENABLE;

  HAL_MPU_ConfigRegion(&MPU_InitStruct);

  /* Enable the MPU */
  HAL_MPU_Enable(MPU_PRIVILEGED_DEFAULT);
}

/**
  * @brief  CPU L1-Cache enable.
  * @param  None
  * @retval None
  */
static void CPU_CACHE_Enable(void)
{
  /* Enable branch prediction */
  SCB->CCR |= (1 << 18);
  __DSB();

  /* Enable I-Cache */
  SCB_EnableICache();

  /* Enable D-Cache */
  SCB_EnableDCache();
}

/**
  * @brief  This function is executed in case of error occurrence.
  * @param  None
  * @retval None
  */
static void Error_Handler(void)
{
  while (1)
  {
    /* LED1 blinks */
    BSP_LED_Toggle(LED1);
    HAL_Delay(100);
  }
}

#ifdef  USE_FULL_ASSERT

/**
  * @brief  Reports the name of the source file and the source line number
  *         where the assert_param error has occurred.
  * @param  file: pointer to the source file name
  * @param  line: assert_param error line source number
  * @retval None
  */
void assert_failed(uint8_t *file, uint32_t line)
{
  /* User can add his own implementation to report the file name and line number,
     ex: printf("Wrong parameters value: file %s on line %d\r\n", file, line) */

  /* Infinite loop */
  while (1)
  {
  }
}
#endif

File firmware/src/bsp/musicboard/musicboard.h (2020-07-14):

/**
  ******************************************************************************
  * @file    stm32746g_discovery.h
  * @author  MCD Application Team
  * @version V1.0.0
  * @date    25-June-2015
  * @brief   This file contains definitions for STM32746G_DISCOVERY's LEDs,
  *          push-buttons and COM ports hardware resources.
  ******************************************************************************
  * @attention
  *
  * <h2><center>&copy; COPYRIGHT(c) 2015 STMicroelectronics</center></h2>
  *
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
  ******************************************************************************
  */ 
  
/* Define to prevent recursive inclusion -------------------------------------*/
#ifndef __MUSICBOARD_H
#define __MUSICBOARD_H

#ifdef __cplusplus
 extern "C" {
#endif

/* Includes ------------------------------------------------------------------*/
#include "stm32f7xx_hal.h"
   
/** @addtogroup BSP
  * @{
  */

/** @addtogroup STM32746G_DISCOVERY
  * @{
  */
      
/** @addtogroup STM32746G_DISCOVERY_LOW_LEVEL
  * @{
  */ 

/** @defgroup STM32746G_DISCOVERY_LOW_LEVEL_Exported_Types STM32746G_DISCOVERY_LOW_LEVEL Exported Types
  * @{
  */
typedef enum 
{
  LED1 = 0,
  LED2 = 1
}Led_TypeDef;

typedef enum 
{
  COM1 = 0,
  COM2 = 1
}COM_TypeDef;
/**
  * @}
  */ 

/** @defgroup STM32746G_DISCOVERY_LOW_LEVEL_Exported_Constants STM32746G_DISCOVERY_LOW_LEVEL Exported Constants
  * @{
  */ 

/** 
  * @brief  Define for STM32746G_DISCOVERY board
  */ 
#if !defined (USE_STM32746G_DISCO)
 #define USE_STM32746G_DISCO
#endif

/** @addtogroup STM32746G_DISCOVERY_LOW_LEVEL_LED
  * @{
  */

#define LEDn                             ((uint8_t)2)

#define LED1_GPIO_PORT                   GPIOA
#define LED1_GPIO_CLK_ENABLE()           __HAL_RCC_GPIOA_CLK_ENABLE()
#define LED1_GPIO_CLK_DISABLE()          __HAL_RCC_GPIOA_CLK_DISABLE()
#define LED1_PIN                         GPIO_PIN_15

#define LED2_GPIO_PORT                   GPIOC
#define LED2_GPIO_CLK_ENABLE()           __HAL_RCC_GPIOC_CLK_ENABLE()
#define LED2_GPIO_CLK_DISABLE()          __HAL_RCC_GPIOC_CLK_DISABLE()
#define LED2_PIN                         GPIO_PIN_12

/**
  * @}
  */


/**
  * @}
  */

/** @addtogroup STM32746G_DISCOVERY_LOW_LEVEL_SIGNAL
  * @{
  */
#define SIGNALn                             ((uint8_t)1)


/**
  * @}
  */ 

/** @addtogroup STM32746G_DISCOVERY_LOW_LEVEL_COM
  * @{
  */
#define COMn                             ((uint8_t)1)

/**
 * @brief Definition for COM port1, connected to USART1
 */ 
#define MIDI_COM1                          USART6
#define MIDI_COM1_CLK_ENABLE()             __HAL_RCC_USART6_CLK_ENABLE()
#define MIDI_COM1_CLK_DISABLE()            __HAL_RCC_USART6_CLK_DISABLE()

#define MIDI_COM1_TX_PIN                   GPIO_PIN_6
#define MIDI_COM1_TX_GPIO_PORT             GPIOC
#define MIDI_COM1_TX_GPIO_CLK_ENABLE()     __HAL_RCC_GPIOC_CLK_ENABLE()
#define MIDI_COM1_TX_GPIO_CLK_DISABLE()    __HAL_RCC_GPIOC_CLK_DISABLE()
#define MIDI_COM1_TX_AF                    GPIO_AF8_USART6

#define MIDI_COM1_RX_PIN                   GPIO_PIN_7
#define MIDI_COM1_RX_GPIO_PORT             GPIOC
#define MIDI_COM1_RX_GPIO_CLK_ENABLE()     __HAL_RCC_GPIOC_CLK_ENABLE()
#define MIDI_COM1_RX_GPIO_CLK_DISABLE()    __HAL_RCC_GPIOC_CLK_DISABLE()
#define MIDI_COM1_RX_AF                    GPIO_AF8_USART6

#define MIDI_COM1_IRQn                     USART6_IRQn

#define MIDI_COMx_CLK_ENABLE(__INDEX__)            do { if((__INDEX__) == COM1) MIDI_COM1_CLK_ENABLE(); } while(0)
#define MIDI_COMx_CLK_DISABLE(__INDEX__)           (((__INDEX__) == 0) ? MIDI_COM1_CLK_DISABLE() : 0)

#define MIDI_COMx_TX_GPIO_CLK_ENABLE(__INDEX__)    do { if((__INDEX__) == COM1) MIDI_COM1_TX_GPIO_CLK_ENABLE(); } while(0)
#define MIDI_COMx_TX_GPIO_CLK_DISABLE(__INDEX__)   (((__INDEX__) == 0) ? MIDI_COM1_TX_GPIO_CLK_DISABLE() : 0)

#define MIDI_COMx_RX_GPIO_CLK_ENABLE(__INDEX__)    do { if((__INDEX__) == COM1) MIDI_COM1_RX_GPIO_CLK_ENABLE(); } while(0)
#define MIDI_COMx_RX_GPIO_CLK_DISABLE(__INDEX__)   (((__INDEX__) == 0) ? MIDI_COM1_RX_GPIO_CLK_DISABLE() : 0)

/* Exported constant IO ------------------------------------------------------*/

#define AUDIO_I2C_ADDRESS                ((uint16_t)0x34) // 0x1a << 1

/* I2C clock speed configuration (in Hz) 
   WARNING: 
   Make sure that this define is not already declared in other files (ie. 
   stm32746g_discovery.h file). It can be used in parallel by other modules. */
#ifndef I2C_SPEED
 #define I2C_SPEED                       ((uint32_t)100000)
#endif /* I2C_SPEED */

/* User can use this section to tailor I2Cx/I2Cx instance used and associated 
   resources */
/* Definition for AUDIO and LCD I2Cx resources */
#define DISCOVERY_AUDIO_I2Cx                             I2C1
#define DISCOVERY_AUDIO_I2Cx_CLK_ENABLE()                __HAL_RCC_I2C1_CLK_ENABLE()
#define DISCOVERY_AUDIO_DMAx_CLK_ENABLE()                __HAL_RCC_DMA1_CLK_ENABLE()
#define DISCOVERY_AUDIO_I2Cx_SCL_SDA_GPIO_CLK_ENABLE()   __HAL_RCC_GPIOB_CLK_ENABLE()
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

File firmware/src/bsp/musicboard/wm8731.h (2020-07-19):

/**
  ******************************************************************************
  * @file    wm8731.h
  * @author  MCD Application Team
  * @version V2.0.0
  * @date    24-June-2015
  * @brief   This file contains all the functions prototypes for the 
  *          wm8731.c driver.
  ******************************************************************************
  * @attention
  *
  * <h2><center>&copy; COPYRIGHT(c) 2015 STMicroelectronics</center></h2>
  *
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
  ******************************************************************************
  */

/* Define to prevent recursive inclusion -------------------------------------*/
#ifndef __WM8994_H
#define __WM8994_H

/* Includes ------------------------------------------------------------------*/
#include "audio_drv.h"

/** @addtogroup BSP
  * @{
  */ 

/** @addtogroup Component
  * @{
  */ 
  
/** @addtogroup WM8994
  * @{
  */

/** @defgroup WM8994_Exported_Types
  * @{
  */

/**
  * @}
  */

/** @defgroup WM8994_Exported_Constants
  * @{
  */ 

/******************************************************************************/
/***************************  Codec User defines ******************************/
/******************************************************************************/
/* Codec output DEVICE */
#define OUTPUT_DEVICE_SPEAKER                 ((uint16_t)0x0001)
#define OUTPUT_DEVICE_HEADPHONE               ((uint16_t)0x0002)
#define OUTPUT_DEVICE_BOTH                    ((uint16_t)0x0003)
#define OUTPUT_DEVICE_AUTO                    ((uint16_t)0x0004)
#define INPUT_DEVICE_DIGITAL_MICROPHONE_1     ((uint16_t)0x0100)
#define INPUT_DEVICE_DIGITAL_MICROPHONE_2     ((uint16_t)0x0200)
#define INPUT_DEVICE_INPUT_LINE_1             ((uint16_t)0x0300)
#define INPUT_DEVICE_INPUT_LINE_2             ((uint16_t)0x0400)

/* Volume Levels values */
#define DEFAULT_VOLMIN                0x00
#define DEFAULT_VOLMAX                0xFF
#define DEFAULT_VOLSTEP               0x04

#define AUDIO_PAUSE                   0
#define AUDIO_RESUME                  1

/* Codec POWER DOWN modes */
#define CODEC_PDWN_HW                 1
#define CODEC_PDWN_SW                 2

/* MUTE commands */
#define AUDIO_MUTE_ON                 1
#define AUDIO_MUTE_OFF                0

/* AUDIO FREQUENCY */
#define AUDIO_FREQUENCY_192K          ((uint32_t)192000)
#define AUDIO_FREQUENCY_96K           ((uint32_t)96000)
#define AUDIO_FREQUENCY_48K           ((uint32_t)48000)
#define AUDIO_FREQUENCY_44K           ((uint32_t)44100)
#define AUDIO_FREQUENCY_32K           ((uint32_t)32000)
#define AUDIO_FREQUENCY_22K           ((uint32_t)22050)
#define AUDIO_FREQUENCY_16K           ((uint32_t)16000)
#define AUDIO_FREQUENCY_11K           ((uint32_t)11025)
#define AUDIO_FREQUENCY_8K            ((uint32_t)8000)  

#define VOLUME_CONVERT(Volume)        (((Volume) > 100)? 100:((uint8_t)(((Volume) * 63) / 100)))
#define VOLUME_IN_CONVERT(Volume)     (((Volume) >= 100)? 239:((uint8_t)(((Volume) * 240) / 100)))

/******************************************************************************/
/****************************** REGISTER MAPPING ******************************/
/******************************************************************************/
/** 
  * @brief  WM8994 ID  
  */  
#define  WM8731_ID    0x8731

/**
  * @brief Device ID Register: Reading from this register will indicate device 
  *                            family ID 8994h
  */
#define WM8731_CHIPID_ADDR                  0x00

/**
  * @}
  */ 

/** @defgroup WM8994_Exported_Macros
  * @{
  */ 
/**
  * @}
  */ 

/** @defgroup WM8994_Exported_Functions
  * @{
  */

#define WM8731_REG_LEFT_LINE_IN 0b0000000
#define WM8731_REG_RIGHT_LINE_IN 0b0000001
#define WM8731_REG_LEFT_HF_OUT 0b0000010
#define WM8731_REG_RIGHT_HF_OUT 0b0000011
#define WM8731_REG_ANALOG_PATH_CTRL 0b0000100
#define WM8731_REG_DIGITAL_PATH_CTRL 0b0000101
#define WM8731_REG_POWER_DOWN_CTRL 0b0000110
#define WM8731_REG_DIGITAL_INTF_FMT 0b0000111
#define WM8731_REG_SAMPLING_CTRL 0b0001000
#define WM8731_REG_ACTIVE_CTRL 0b0001001
#define WM8731_REG_RESET 0b0001111

/*------------------------------------------------------------------------------
                           Audio Codec functions 
------------------------------------------------------------------------------*/
/* High Layer codec functions */
uint32_t wm8731_Init(uint16_t DeviceAddr, uint16_t OutputInputDevice, uint8_t Volume, uint32_t AudioFreq);
void     wm8731_DeInit(void);
uint32_t wm8731_ReadID(uint16_t DeviceAddr);
uint32_t wm8731_Play(uint16_t DeviceAddr, uint16_t* pBuffer, uint16_t Size);
uint32_t wm8731_Pause(uint16_t DeviceAddr);
uint32_t wm8731_Resume(uint16_t DeviceAddr);
uint32_t wm8731_Stop(uint16_t DeviceAddr, uint32_t Cmd);
uint32_t wm8731_SetVolume(uint16_t DeviceAddr, uint8_t Volume);
uint32_t wm8731_SetMute(uint16_t DeviceAddr, uint32_t Cmd);
uint32_t wm8731_SetOutputMode(uint16_t DeviceAddr, uint8_t Output);
uint32_t wm8731_SetFrequency(uint16_t DeviceAddr, uint32_t AudioFreq);
uint32_t wm8731_Reset(uint16_t DeviceAddr);

/* AUDIO IO functions */
void    AUDIO_IO_Init(void);
void    AUDIO_IO_DeInit(void);
void    AUDIO_IO_Write(uint8_t Addr, uint16_t Reg, uint16_t Value);
uint8_t AUDIO_IO_Read(uint8_t Addr, uint16_t Reg);
void    AUDIO_IO_Delay(uint32_t Delay);

/* Audio driver structure */
extern AUDIO_DrvTypeDef   wm8731_drv;

#endif /* __WM8994_H */

/**
  * @}
  */ 

/**
  * @}
  */ 

/**
  * @}
  */

/**
  * @}
  */ 

/************************ (C) COPYRIGHT STMicroelectronics *****END OF FILE****/

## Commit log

2020-06-11 add pdf schematics
2020-06-12 add extension to board + add former fluidsynth
    [musicboard.kicad_pcb, musicboard.sch]
2020-06-14 use usb mini b + add usb header
    [musicboard.kicad_pcb, musicboard.sch]
2020-06-14 update schematics
    [musicboard.sch]
2020-06-14 add vdda
    [musicboard.kicad_pcb]
2020-06-15 realign label
    [musicboard.kicad_pcb]
2020-07-14 fix audio async feedback + improve sysex support
    [main.c, musicboard.c, musicboard.h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]

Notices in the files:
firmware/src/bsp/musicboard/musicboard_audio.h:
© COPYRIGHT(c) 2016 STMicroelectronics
